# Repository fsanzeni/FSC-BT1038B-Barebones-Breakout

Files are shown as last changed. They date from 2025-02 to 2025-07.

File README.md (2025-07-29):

# FSC-BT1038B Breakout Board

_A breakout board designed using KiCad. AIM: test out Auracast protocols to (eventually) build a Bluetooth speaker_

## Overview

This repository contains the design files for a custom breakout board created in KiCad. The board is intended for evaluating the [Feasycom FSC-BT1038B module](https://www.feasycom.com/fsc-bt1038b). All pins are broken out and grouped for your convenience.

## Features

-   **Modern IC:** board based on the [QCC3084](https://www.qualcomm.com/products/internet-of-things/consumer/audio/qcc30xx-series/qcc3084) IC by Qualcomm.
-   **(Relatively) Compact Design:** ~60x45mm
-   **Voltage Compatibility:** it accepts 5v USB, stepped to 3.3v via an AMS1117. The FSC-BT1038B offers additional 1.8v out (TP1) and 3.3v out (~50mA max, TP2).
-   **Pinout:** all pins are broken out and labeled on the silkscreen. 
-   **Additional Features:** three status LEDs connected to the LED0, LED1 and LED2 pins. Three user buttons are also present on the board (see silkscreen labelling).

## Schematic
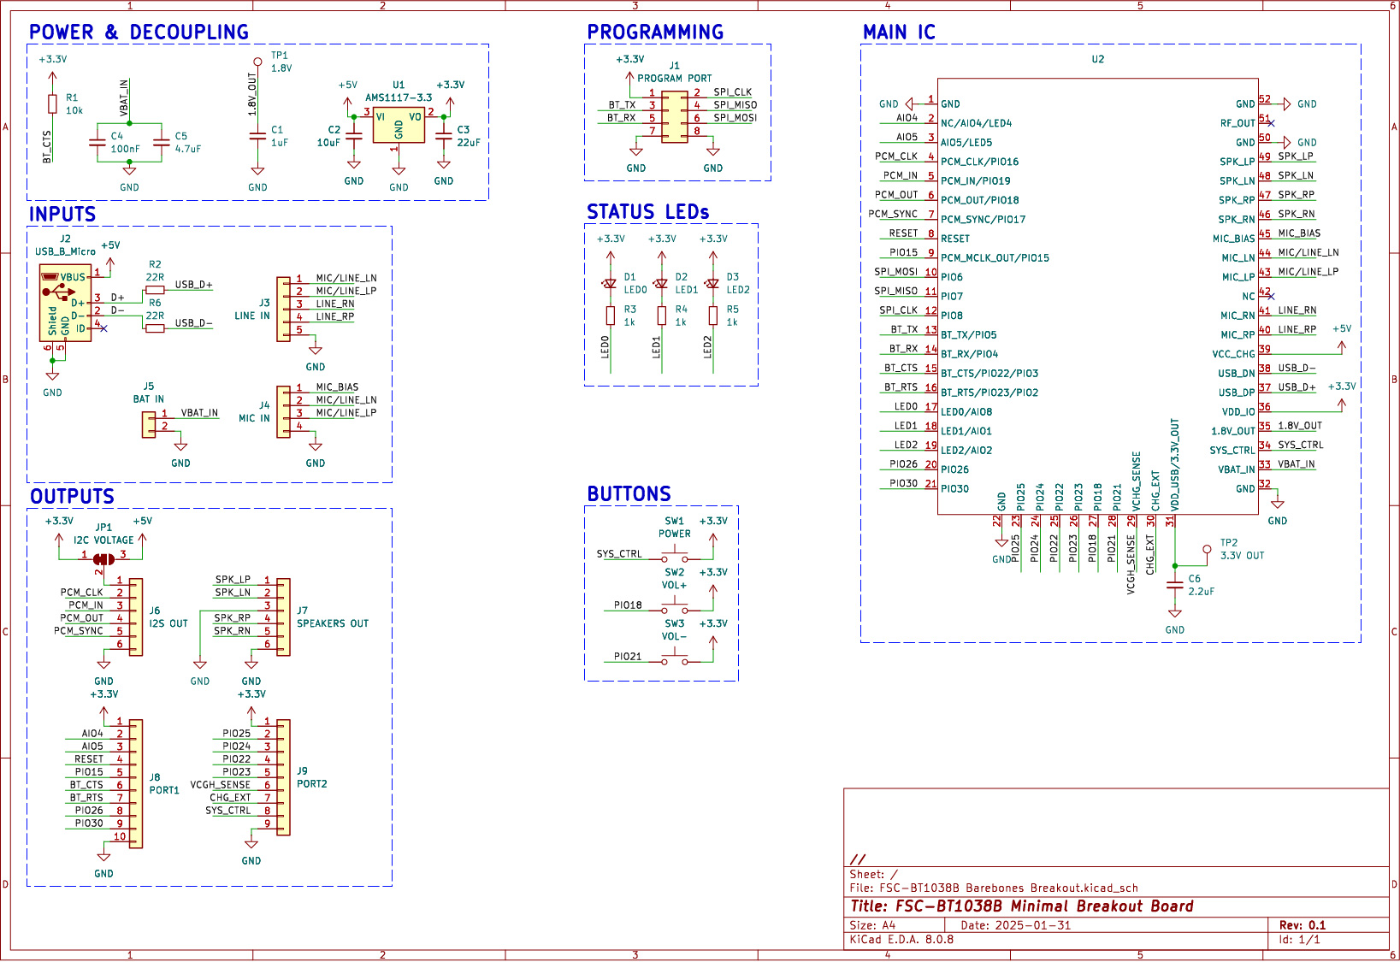
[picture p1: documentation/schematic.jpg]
FSC-BT1038B Breakout Board Schematic


## Checklist

### 🛠️ Project Status

| Component | Status |
| --- | --- |
| Schematic | ✅ Done |
| PCB Layout | ✅ Done |
| Gerber Files | ✅ Generated |
| Fabrication | ✅ Done |
| Assembly | ✅ Done |
| Testing | ✅ Done |
| Firmware | 🔄 In Progress |
| Documentation | 🔄 In Progress |

Please note - the board has been tested and functions as intended.

## Getting Started

### Prerequisites

Ensure you have the following installed:

- [KiCad](https://www.kicad.org/) (version 8.0 or later)
- Add the custom libraries to your (local) project. They're included in this repo in the hardware/libraries/ folder

## Files & Directory Structure

```
📂 kicad-breakout/
 ├── 📂 documentation/			# Documentation (WIP) - find in here the schematic (pdf, svg and jpg)
 ├── 📂 firmware/				# Firmware
 ├── 📂 hardware/				# KiCad design files
 	├── 📂 bom/					# Interactive BOM (html)
 	├── 📂 fabrication/			# Fabrication files
 	├── 📂 libraries/			# Please don't forget to include these!
```

## Contribution

Contributions are welcome! Feel free to submit a pull request or open an issue for discussion.

## License

This project is licensed under the [CERN-OHL-S v2](https://ohwr.org/cern_ohl_s_v2.txt).

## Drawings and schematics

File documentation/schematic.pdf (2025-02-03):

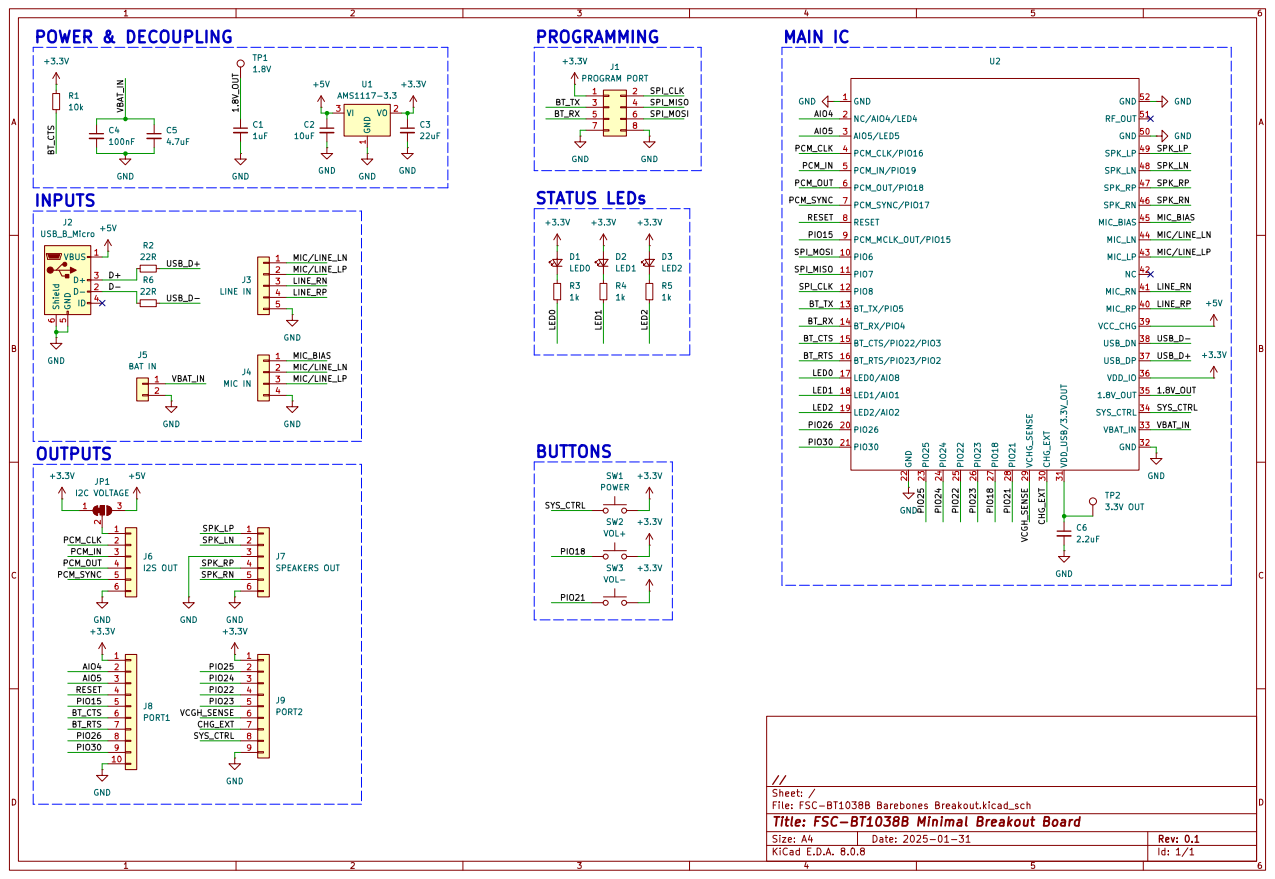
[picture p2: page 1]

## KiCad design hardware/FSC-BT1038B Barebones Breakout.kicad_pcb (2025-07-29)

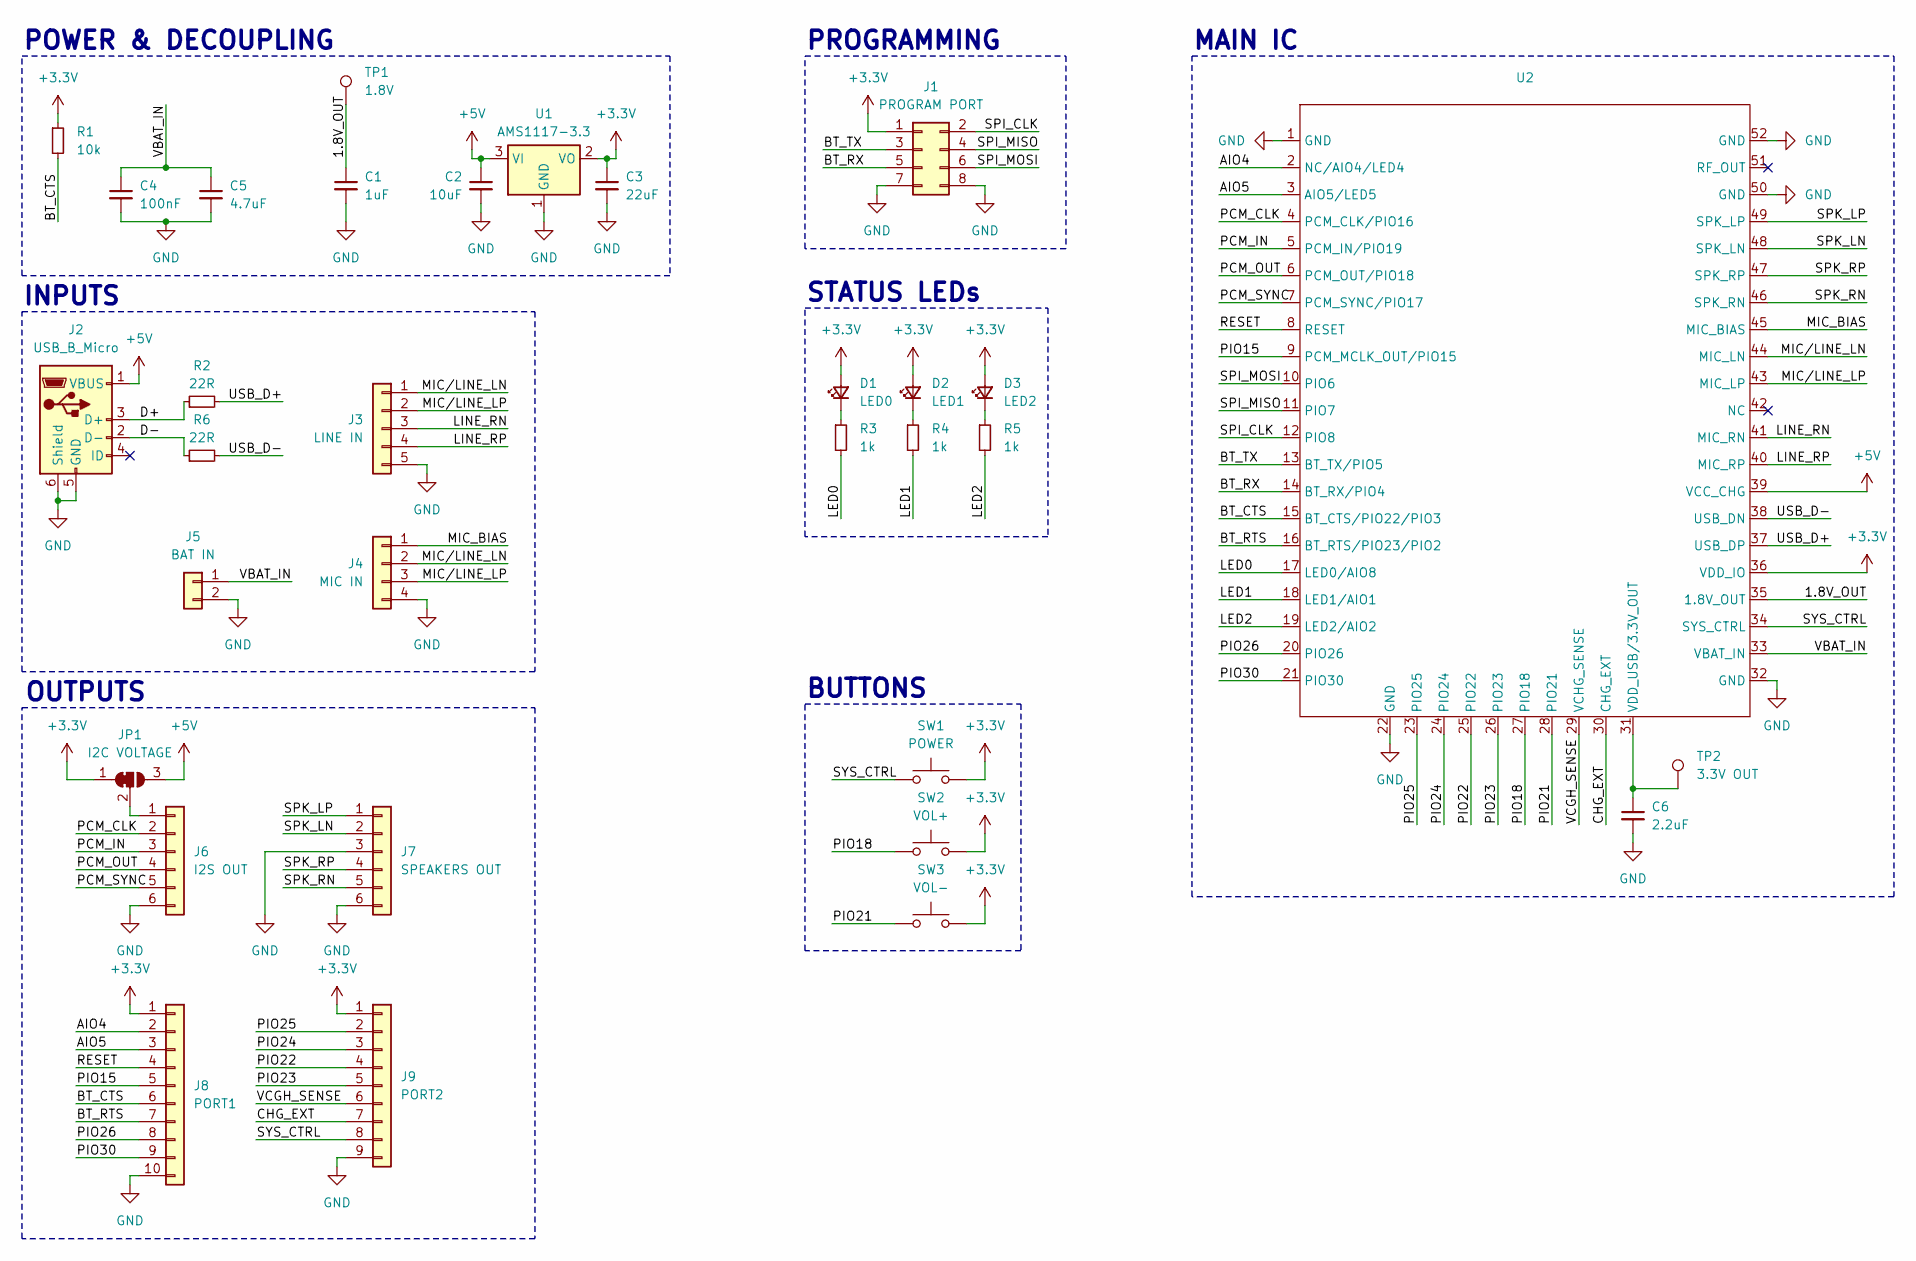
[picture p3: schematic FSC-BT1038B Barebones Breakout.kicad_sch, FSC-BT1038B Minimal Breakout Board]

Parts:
C1: 1uF; C_0603_1608Metric_Pad1.08x0.95mm_HandSolder
C2: 10uF; C_0603_1608Metric_Pad1.08x0.95mm_HandSolder
C3: 22uF; C_0603_1608Metric_Pad1.08x0.95mm_HandSolder
C4: 100nF; C_0603_1608Metric_Pad1.08x0.95mm_HandSolder
C5: 4.7uF; C_0603_1608Metric_Pad1.08x0.95mm_HandSolder
C6: 2.2uF; C_0603_1608Metric_Pad1.08x0.95mm_HandSolder
D1: LED0; LED_0603_1608Metric_Pad1.05x0.95mm_HandSolder
D2: LED1; LED_0603_1608Metric_Pad1.05x0.95mm_HandSolder
D3: LED2; LED_0603_1608Metric_Pad1.05x0.95mm_HandSolder
J1: PROGRAM PORT; PinSocket_2x04_P2.54mm_Vertical
J2: USB_B_Micro; KH-MICRO5P-JN
J3: LINE IN; PinSocket_1x05_P2.54mm_Vertical
J4: MIC IN; PinSocket_1x04_P2.54mm_Vertical
J5: BAT IN; PinSocket_1x02_P2.54mm_Vertical
J6: I2S OUT; PinSocket_1x06_P2.54mm_Vertical
J7: SPEAKERS OUT; PinSocket_1x06_P2.54mm_Vertical
J8: PORT1; PinSocket_1x10_P2.54mm_Vertical
J9: PORT2; PinSocket_1x09_P2.54mm_Vertical
JP1: I2C VOLTAGE; SolderJumper-3_P1.3mm_Bridged2Bar12_Pad1.0x1.5mm_NumberLabe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
R1: 10k; R_0603_1608Metric_Pad0.98x0.95mm_HandSolder
R2, R6: 22R; R_0603_1608Metric_Pad0.98x0.95mm_HandSolder
R3, R4, R5: 1k; R_0603_1608Metric_Pad0.98x0.95mm_HandSolder
SW1: POWER; TS3425BA
SW2: VOL+; TS3425BA
SW3: VOL-; TS3425BA
TP1: 1.8V; TestPoint_Pad_D1.5mm
TP2: 3.3V OUT; TestPoint_Pad_D1.5mm
U1: AMS1117-3.3; SOT-223-3_TabPin2
U2: FSC-BT1038B

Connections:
+3.3V: C3.1, D1.2 (A), D2.2 (A), D3.2 (A), J1.1, J8.1, J9.1, JP1.1 (A), R1.1, SW1.2, SW2.2, SW3.2, U1.2 (VO), U2.36 (VDD_IO)
+5V: C2.1, J2.1 (VBUS), JP1.3 (B), U1.3 (VI), U2.39 (VCC_CHG)
/1.8V_OUT: C1.1, TP1.1, U2.35 (1.8V_OUT)
/AIO4: J8.2, U2.2 (NC/AIO4/LED4)
/AIO5: J8.3, U2.3 (AIO5/LED5)
/BT_CTS: J8.6, R1.2, U2.15 (BT_CTS/PIO22/PIO3)
/BT_RTS: J8.7, U2.16 (BT_RTS/PIO23/PIO2)
/BT_RX: J1.5, U2.14 (BT_RX/PIO4)
/BT_TX: J1.3, U2.13 (BT_TX/PIO5)
/CHG_EXT: J9.7, U2.30 (CHG_EXT)
/D+: J2.3 (D+), R2.1
/D-: J2.2 (D-), R6.1
/LED0: R3.2, U2.17 (LED0/AIO8)
/LED1: R4.2, U2.18 (LED1/AIO1)
/LED2: R5.2, U2.19 (LED2/AIO2)
/LINE_RN: J3.3, U2.41 (MIC_RN)
/LINE_RP: J3.4, U2.40 (MIC_RP)
/MIC_BIAS: J4.1, U2.45 (MIC_BIAS)
/MIC/LINE_LN: J3.1, J4.2, U2.44 (MIC_LN)
/MIC/LINE_LP: J3.2, J4.3, U2.43 (MIC_LP)
/PCM_CLK: J6.2, U2.4 (PCM_CLK/PIO16)
/PCM_IN: J6.3, U2.5 (PCM_IN/PIO19)
/PCM_OUT: J6.4, U2.6 (PCM_OUT/PIO18)
/PCM_SYNC: J6.5, U2.7 (PCM_SYNC/PIO17)
/PIO15: J8.5, U2.9 (PCM_MCLK_OUT/PIO15)
/PIO18: SW2.1, U2.27 (PIO18)
/PIO21: SW3.1, U2.28 (PIO21)
/PIO22: J9.4, U2.25 (PIO22)
/PIO23: J9.5, U2.26 (PIO23)
/PIO24: J9.3, U2.24 (PIO24)
/PIO25: J9.2, U2.23 (PIO25)
/PIO26: J8.8, U2.20 (PIO26)
/PIO30: J8.9, U2.21 (PIO30)
/RESET: J8.4, U2.8 (RESET)
/SPI_CLK: J1.2, U2.12 (PIO8)
/SPI_MISO: J1.4, U2.11 (PIO7)
/SPI_MOSI: J1.6, U2.10 (PIO6)
/SPK_LN: J7.2, U2.48 (SPK_LN)
/SPK_LP: J7.1, U2.49 (SPK_LP)
/SPK_RN: J7.5, U2.46 (SPK_RN)
/SPK_RP: J7.4, U2.47 (SPK_RP)
/SYS_CTRL: J9.8, SW1.1, U2.34 (SYS_CTRL)
/USB_D+: R2.2, U2.37 (USB_DP)
/USB_D-: R6.2, U2.38 (USB_DN)
/VBAT_IN: C4.1, C5.1, J5.1, U2.33 (VBAT_IN)
/VCGH_SENSE: J9.6, U2.29 (VCHG_SENSE)
GND: C1.2, C2.2, C3.2, C4.2, C5.2, C6.2, J1.7, J1.8, J2.5 (GND), J2.6 (Shield), J3.5, J4.4, J5.2, J6.6, J7.3, J7.6, J8.10, J9.9, U1.1 (GND), U2.1 (GND), U2.22 (GND), U2.32 (GND), U2.50 (GND), U2.52 (GND)
unnamed: D1.1 (K), R3.1
unnamed: D2.1 (K), R4.1
unnamed: D3.1 (K), R5.1
unnamed: J6.1, JP1.2 (C)
unnamed: C6.1, TP2.1, U2.31 (VDD_USB/3.3V_OUT)

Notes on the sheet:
MAIN IC
POWER & DECOUPLING
INPUTS
OUTPUTS
STATUS LEDs
BUTTONS
PROGRAMMING

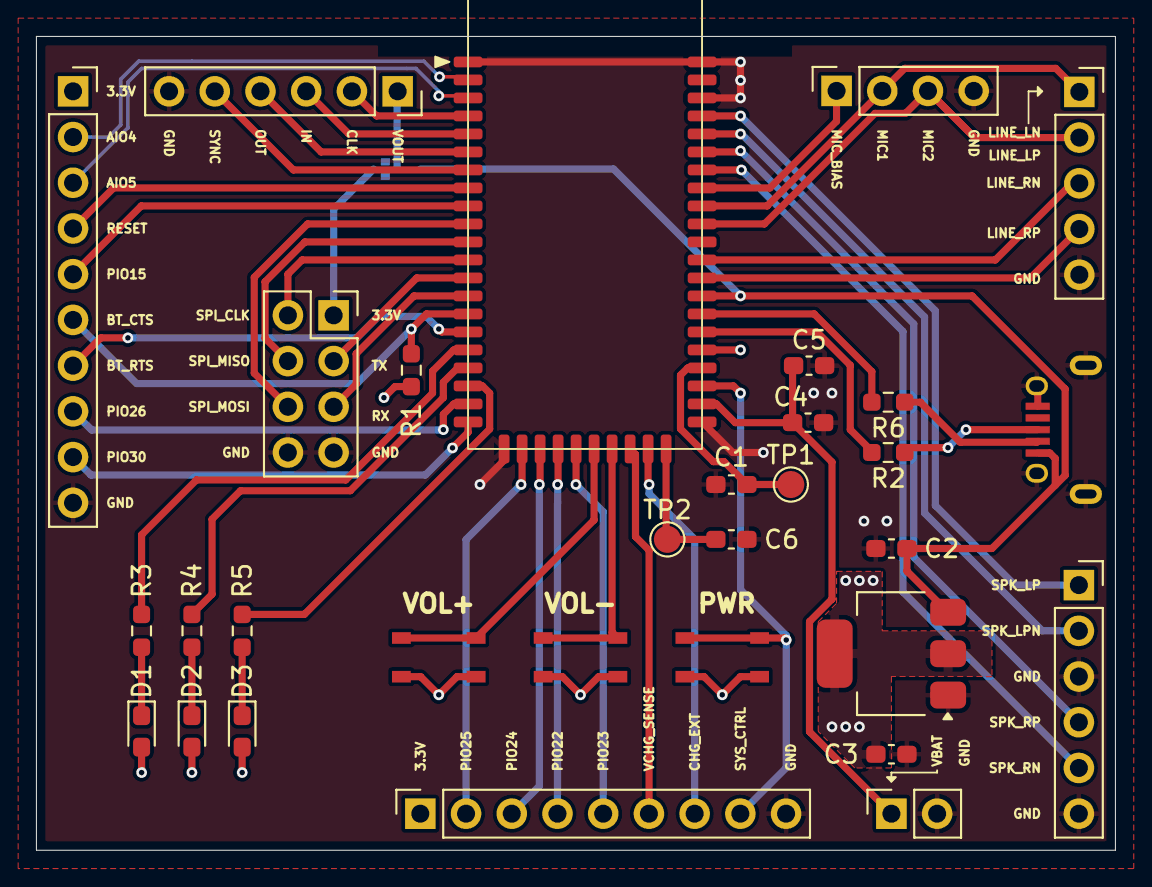
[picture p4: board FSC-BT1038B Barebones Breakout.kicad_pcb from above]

Board: 4 copper layers, 59.9 x 45.2 mm, 32 parts (1 on the bottom side), 52 nets.

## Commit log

2025-02-03 Added schematics (pdf, svg & jpg). Edited README
2025-07-29 corrected schematic
    [FSC-BT1038B Barebones Breakout.kicad_pcb, FSC-BT1038B Barebones Breakout.kicad_sch]
